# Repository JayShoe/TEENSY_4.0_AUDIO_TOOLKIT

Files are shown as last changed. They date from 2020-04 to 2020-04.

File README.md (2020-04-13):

# Teensy 4.0 Audio Toolkit and Shield
Licensed under CC BY-NC-SA 4.0
https://creativecommons.org/licenses/by-nc-sa/4.0/
Project by Jay Shoemaker

*Project is incomplete, accepting feedback now!

The Teensy 4.0 Audio Toolkit and Shield is part of an open source project for learning about, designing, and rapid-prototyping custom Audio PCBs using the Teensy Audio Library. This kit exposes key features of the Teensy commonly used for audio including USB Host Input, MIDI In, Midi Out, Midi Through, SPDIF, and Toslink. The board also includes an SD Memory Card reader, RAM/Memory, and a Power Supply. Plus, the schematic points out the key pins for connecting your own audio chips to the Teensy. This project is just exposing the hardware. Some functions may require additional work on the Teensy Audio Library or your custom code.  
 
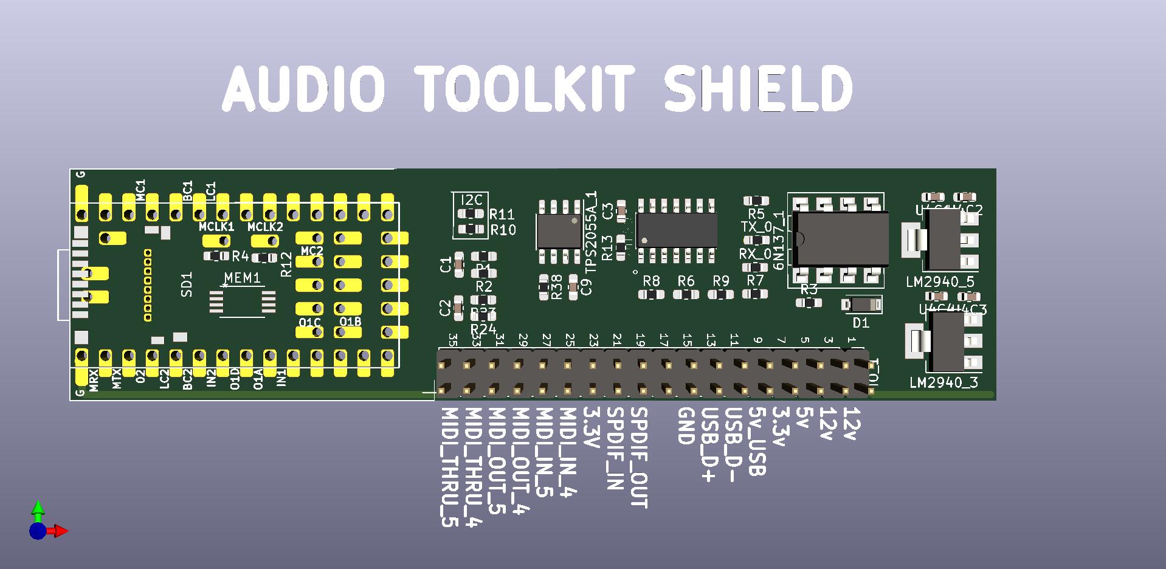
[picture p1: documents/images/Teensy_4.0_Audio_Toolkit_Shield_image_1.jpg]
Audio Toolkit Shield


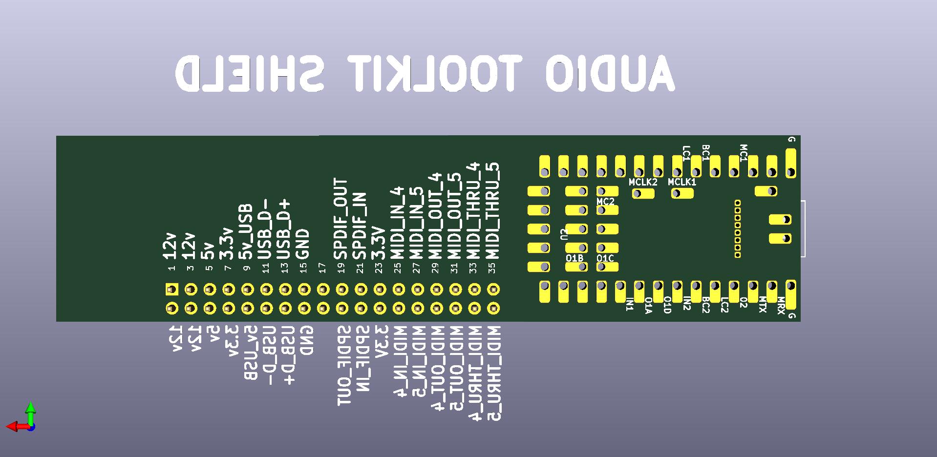
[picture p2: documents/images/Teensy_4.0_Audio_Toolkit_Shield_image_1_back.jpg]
Audio Toolkit Shield Back

 
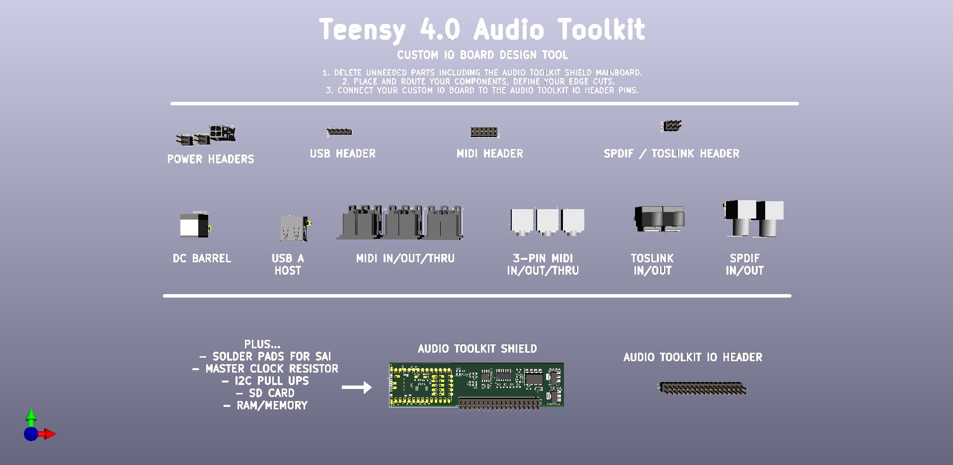
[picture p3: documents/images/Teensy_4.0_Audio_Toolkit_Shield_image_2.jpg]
Audio Toolkit


# Teensy Audio Toolkit and Shield's Key Features
 * Open Source CC BY-NC-SA 4.0
 * Stackable Design – To easily integrate with other stackable modules including DAC, ADC, Codec, Bluetooth, etc. 
 * Starting Point for Custom IO Panels – All inputs/outputs are only exposed as header pins. Use of a custom daughterboard, dongle, or soldering directly to the Audio Toolkit Mainboard to expose the desired jacks or ports. 
  * SD Card Reader  - via DM3D-SF Hirose Electric Co Ltd. 
  * Memory – via W25Q128JV, W25Q128FV, or 23LC1024 RAM. 
  * USB Host – via standard pinout USB Header and USB A connector and includes a TPS2055A current limiter chip. 
  * SPDIF Input and Output – via header, Coax, or Toslink.
  * MIDI In, Out, and Through – via header, DIN 5, or 3.5mm 3-pin Mini MIDI and includes an optocoupler (6N137) and a logic gate (74LS00) for proper termination. 
  * Power Supply – 1 Amp regulator for both 5V and 3.3V rails (LM2940) with an input voltage range of 6 V to 26 V. 
 * Footprints, 3d Models, and Schematics included. 
 * SAI Connectivity and Labels. The teensy footprint has been modified to include wide pads and pin information for standard I2S connectivity. Solder wire to those pads for an easy and secure connection to external DAC/ADC/CODEC/ETC. 
  * Master Clock - 100 Ohm resistors installed on MCLK1 and MCLK2 lines for easy connectivity. 
  * i2C - Pull up resistors on board for easy connectivity.
# Daughterboards with Jacks/Ports
The Audio Toolkit Shield’s header allows simple connections to one or more daughter boards. The mainboard and daughter board’s source and gerbers will be publicly available on the project repository. Pre-assembled boards will be made available (when tested/complete). Create your own daughterboard using the toolkit as a starting point. (Be sure to contribute back your modifications!)
## Designing a Custom Daughterboard
1.	Delete unneeded parts including the Audio Toolkit Mainboard. 
2.	Place and route your components. Define your edge cuts. Order your board. 
3.	Connect your customer IO Board to the Audio Toolkit Mainboard IO Header. 
## Audio Toolkit Notes
-	Use pre-built IO boards found within the project’s repository. 
-	Use the “Audio Toolkit IO Header” to stack your custom IO Board on top of the mainboard via the headers. 
-	Use the individual headers to create smaller custom IO Boards and link your project via ribbon cables, etc. 
-	Use the schematic to create your own entirely new custom Audio Toolkit or integrate it into your own project.

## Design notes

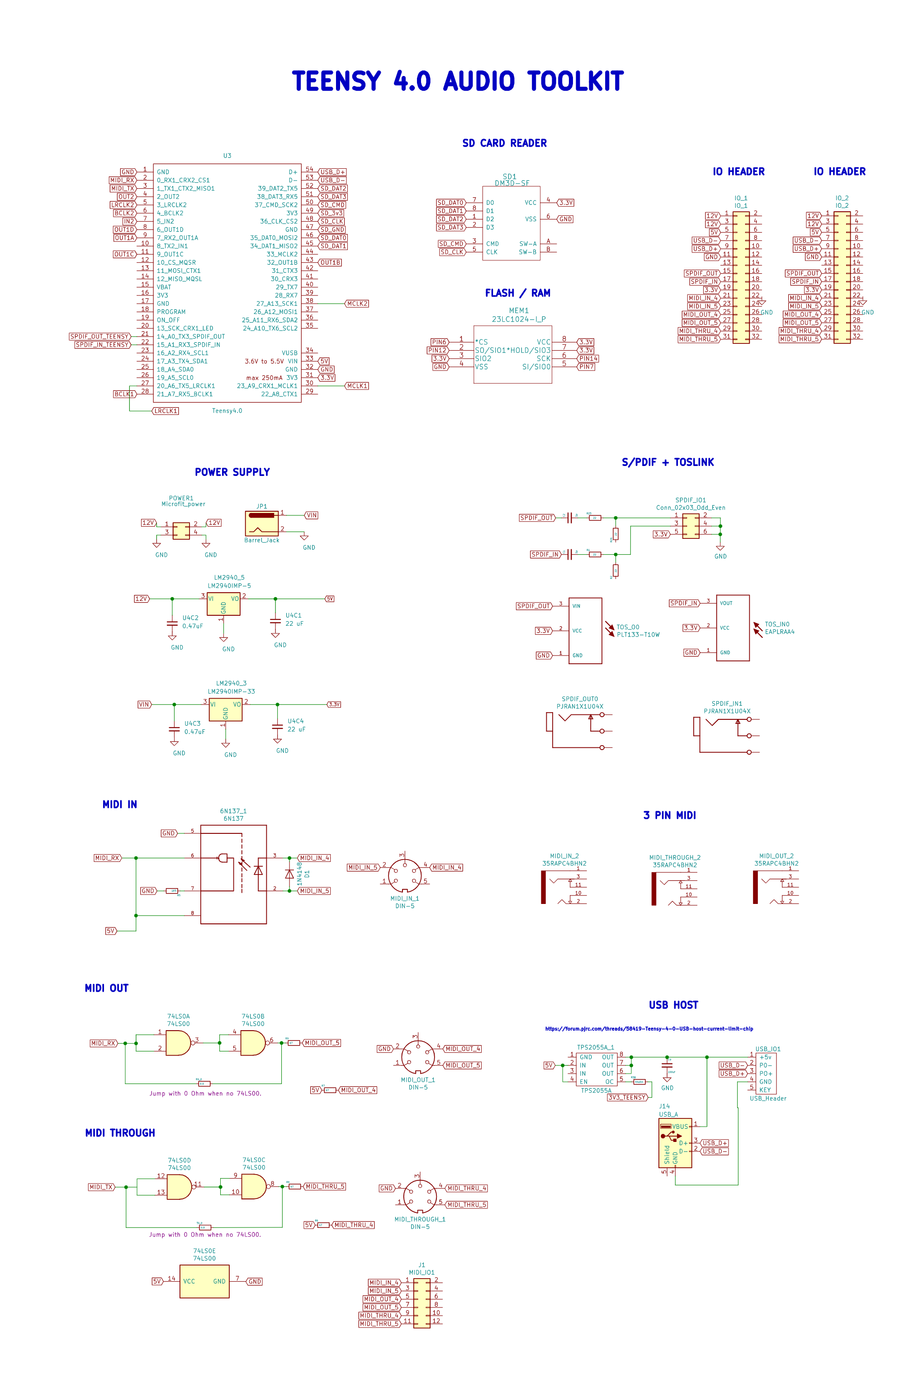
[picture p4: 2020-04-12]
documents/images/Teensy_4.0_Audio_Toolkit_Shield_Schematic_1.png

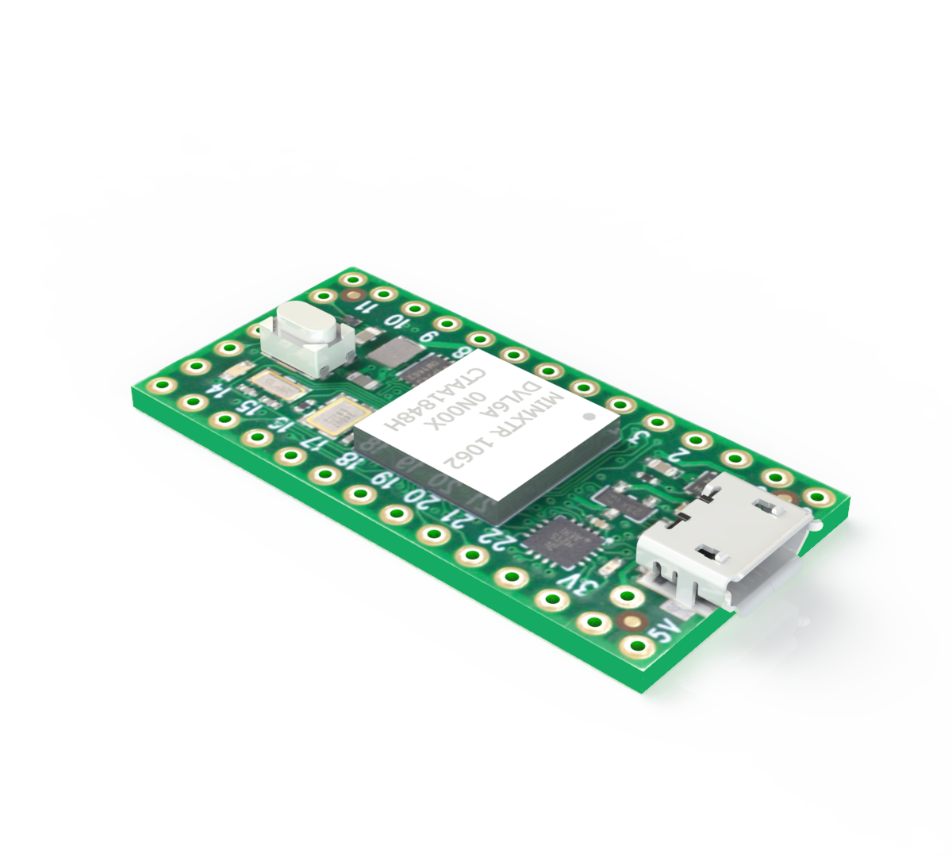
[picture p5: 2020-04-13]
3d_models/teensy-4-0-1.snapshot.3/Teensy_4.0/Renders/Teensy_4.0.png

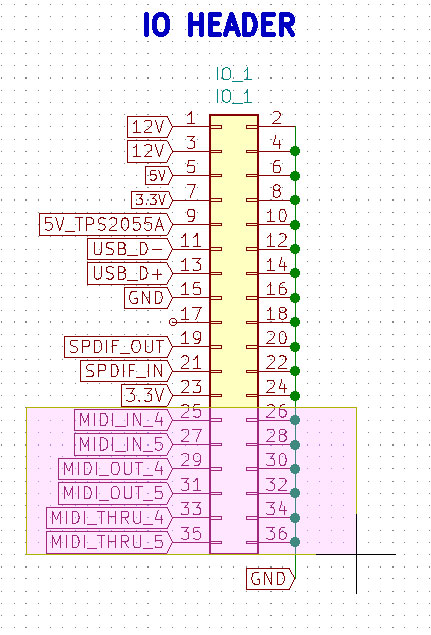
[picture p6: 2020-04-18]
documents/images/audio_toolkit_io_header.jpg

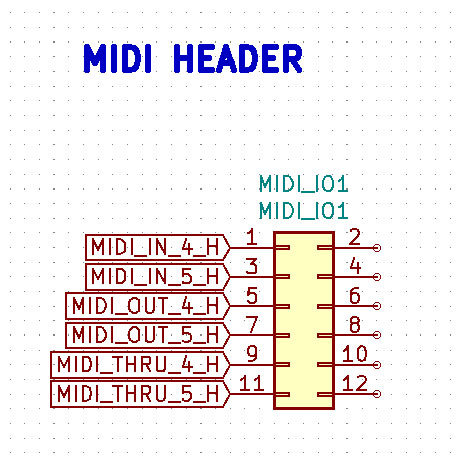
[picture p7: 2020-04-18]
documents/images/midi_header.jpg

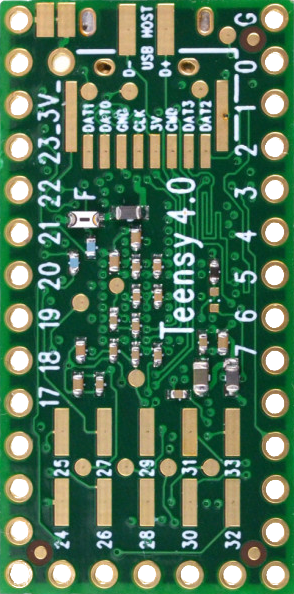
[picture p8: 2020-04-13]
3d_models/teensy-4-0-1.snapshot.3/Teensy_4.0/Teensy_4.0_Decal/Teensy_4.0_Back.png

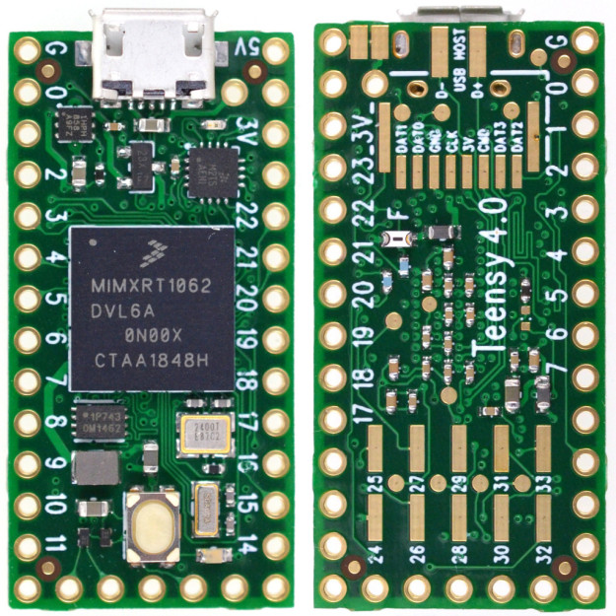
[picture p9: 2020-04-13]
3d_models/teensy-4-0-1.snapshot.3/Teensy_4.0/Teensy_4.0_Decal/teensy40-launch-frontandback-thumb.jpg

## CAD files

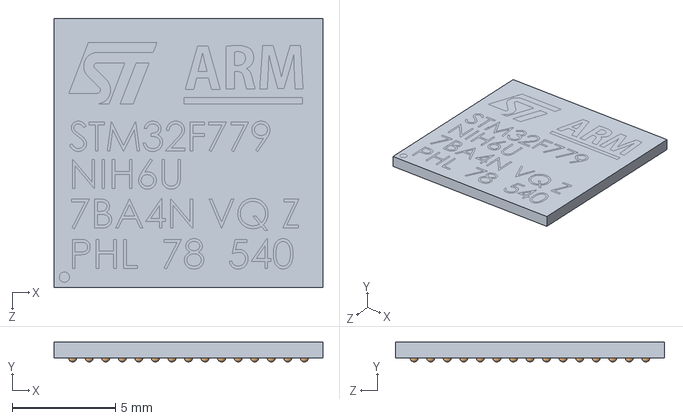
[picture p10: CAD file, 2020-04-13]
3d_models/teensy-4-0-1.snapshot.3/Teensy_4.0/STM32F779NIHx.SLDASM
13.0 x 0.96 x 13.0 mm
ball x 216

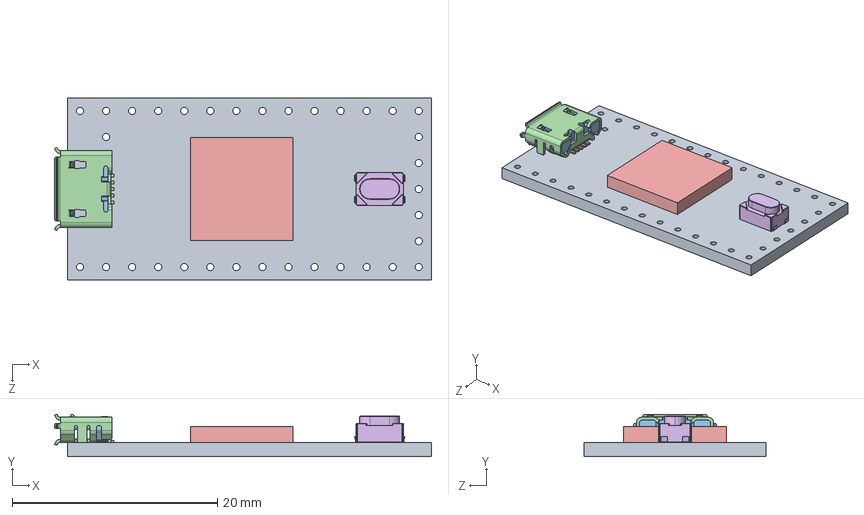
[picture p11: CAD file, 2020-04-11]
3d_models/teensy-4-0-1.snapshot.3/Teensy_4.0/Teensy_4.0_Assembly.STEP
36.8 x 4.12 x 17.7 mm
Teensy_4.0_PCB
Micro USB-B Female 5Pin SMD
NXP iMXRT1062
SKRPACE010 v4

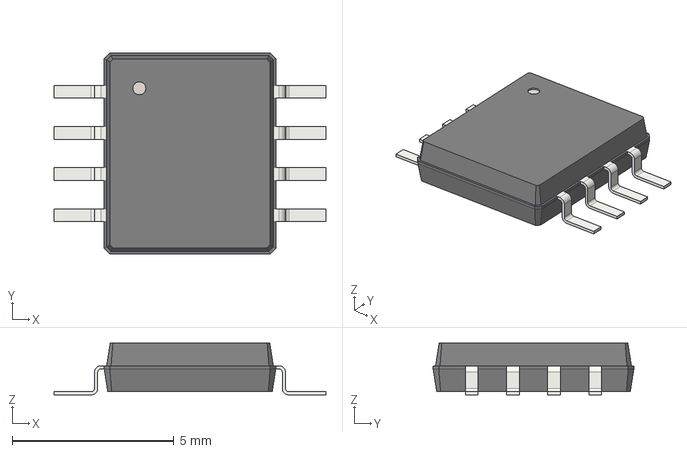
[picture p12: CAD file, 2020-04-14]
3d_models/SO-8_5.3x6.2mm_P1.27mm.step
8.40 x 6.20 x 1.60 mm

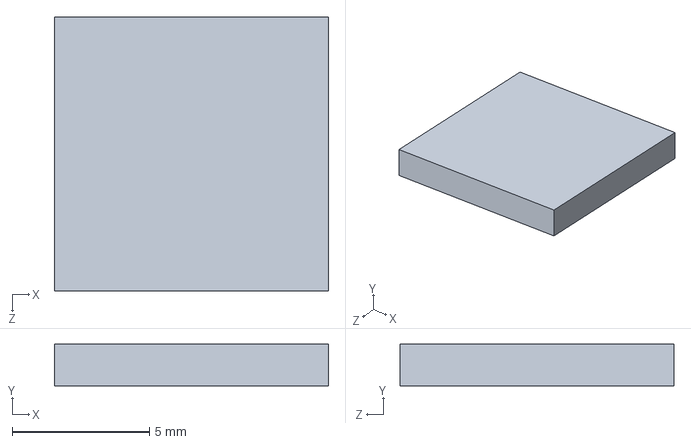
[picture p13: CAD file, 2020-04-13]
3d_models/teensy-4-0-1.snapshot.3/Teensy_4.0/NXP iMXRT1062.SLDPRT
10.0 x 1.52 x 10.0 mm

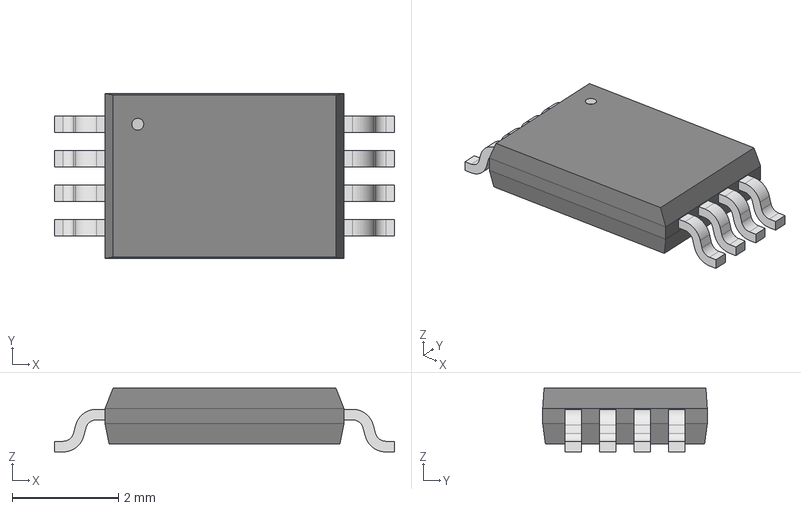
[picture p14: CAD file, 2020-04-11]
lib_sch/ul_23LC1024IST/2020-04-10_17-26-26/STEP/TSSOP8_MC.step
6.40 x 3.10 x 1.20 mm

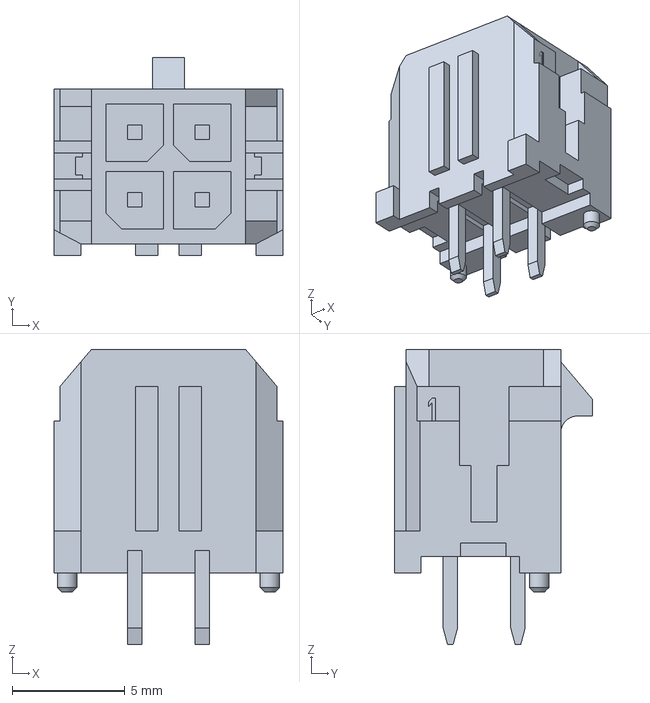
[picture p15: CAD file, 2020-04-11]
3d_models/MicroFit3-43045-0428.stp
10.1 x 8.77 x 13.1 mm

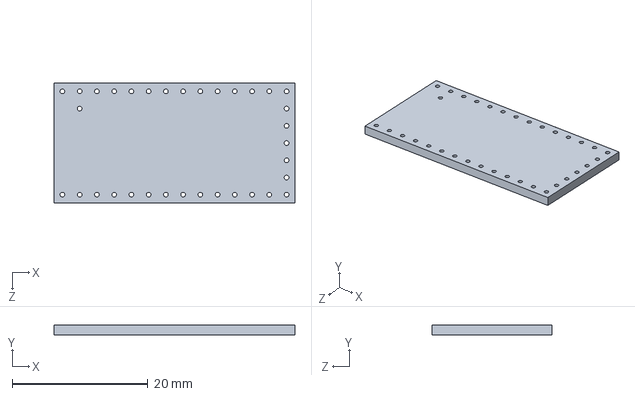
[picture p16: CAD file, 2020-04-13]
3d_models/teensy-4-0-1.snapshot.3/Teensy_4.0/Teensy_4.0_PCB.SLDPRT
35.5 x 1.40 x 17.7 mm

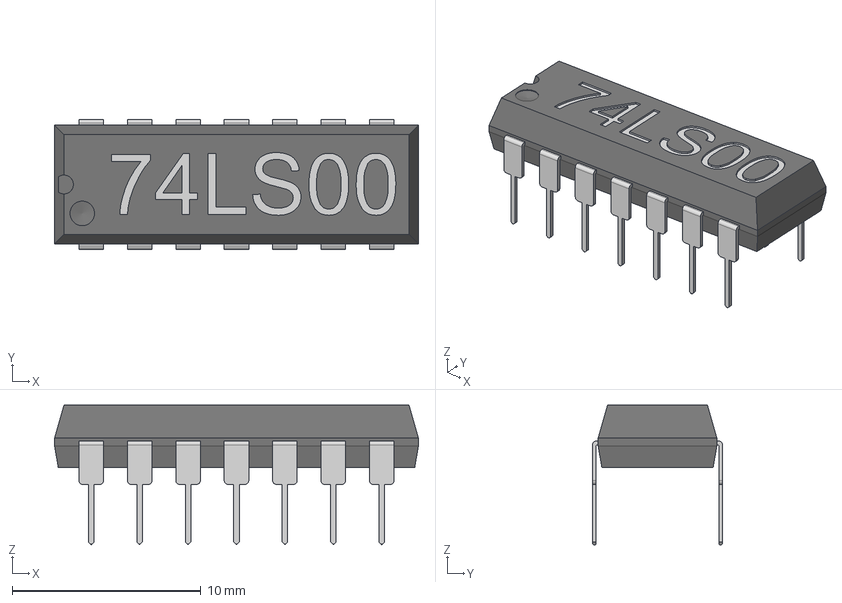
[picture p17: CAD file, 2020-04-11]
3d_models/74LS00.step
19.3 x 6.90 x 7.40 mm

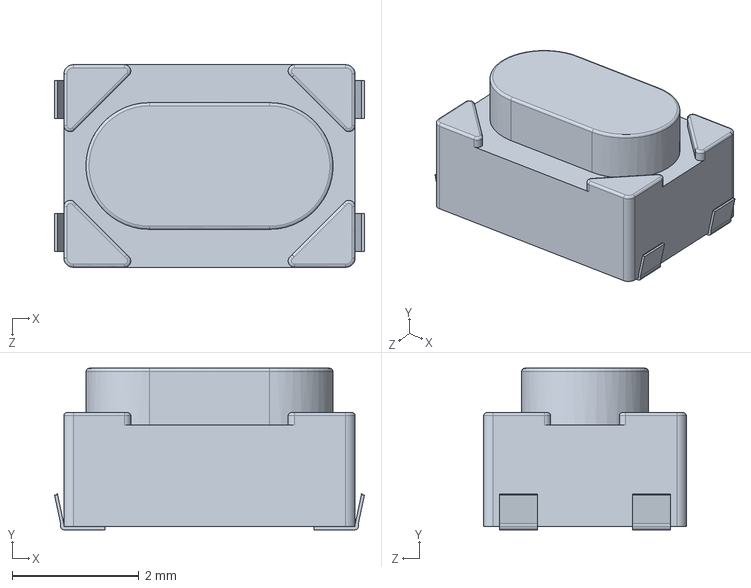
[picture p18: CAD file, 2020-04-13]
3d_models/teensy-4-0-1.snapshot.3/Teensy_4.0/SKRPACE010 v4.SLDPRT
4.89 x 2.55 x 3.20 mm

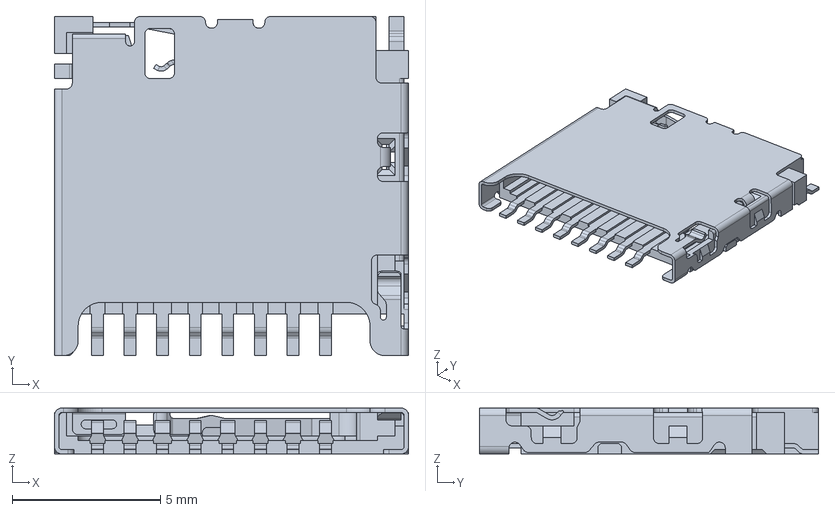
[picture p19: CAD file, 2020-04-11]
3d_models/SD_CARD_DM3D-SF.step
11.9 x 11.4 x 1.55 mm

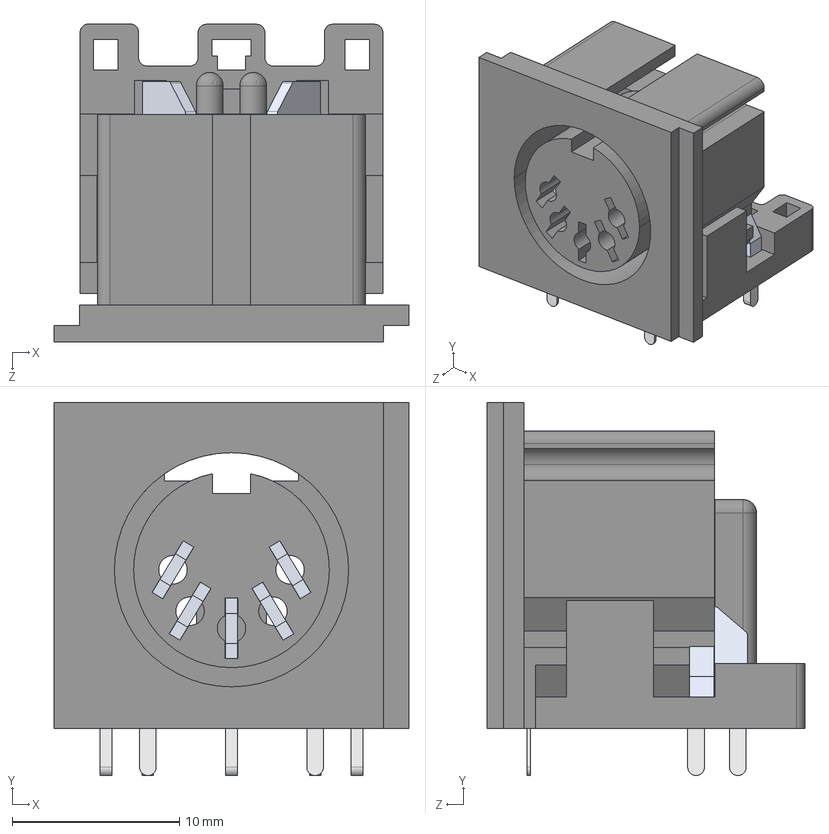
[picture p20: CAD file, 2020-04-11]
3d_models/DIN-5.STEP
21.2 x 22.3 x 19.0 mm
DIN5 A
DIN5 B
DIN5 C
DIN D x 2
DIN E x 2
DIN EE x 2
DIN G
DIN DD x 2

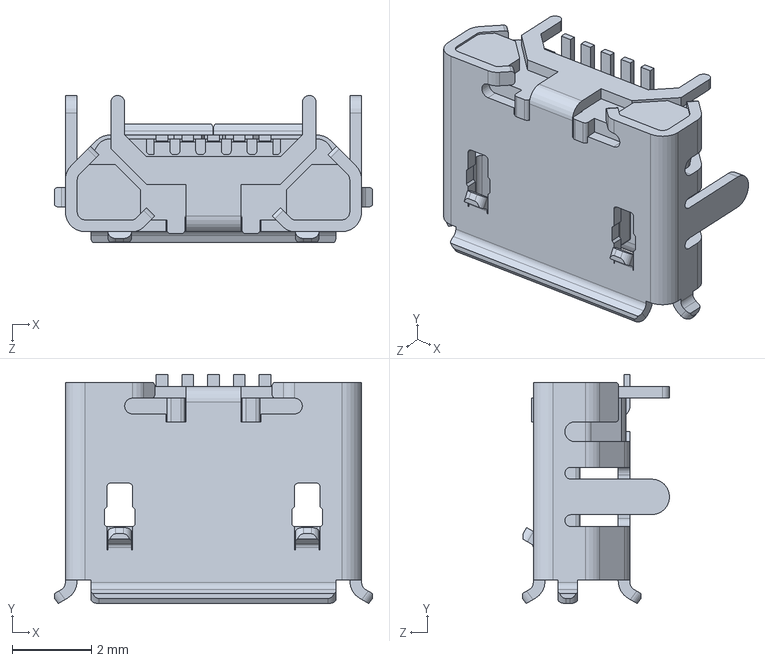
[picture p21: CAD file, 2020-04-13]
3d_models/teensy-4-0-1.snapshot.3/Teensy_4.0/Micro USB-B Female 5Pin SMD.SLDPRT
8.05 x 5.80 x 3.72 mm

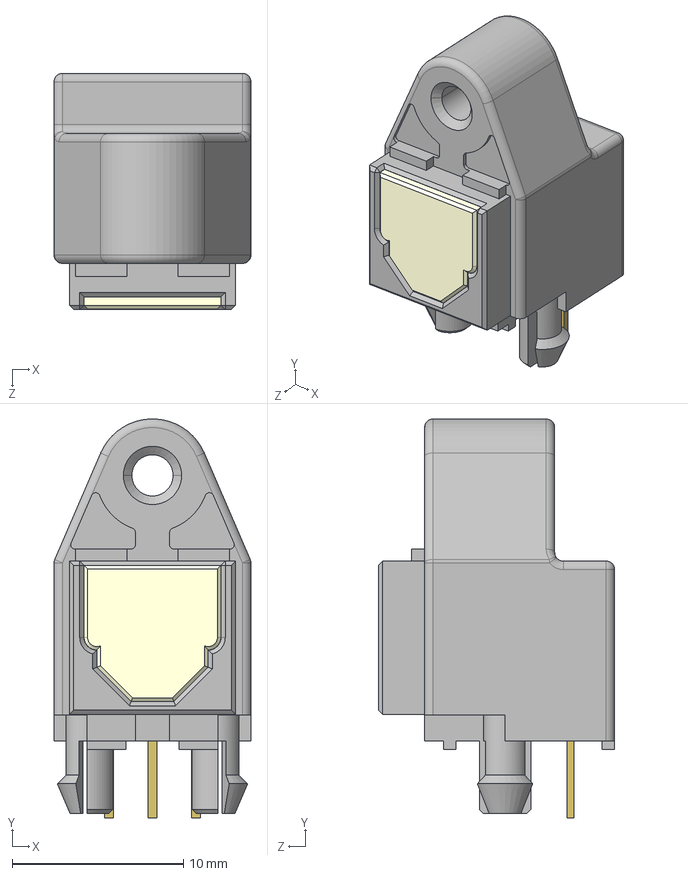
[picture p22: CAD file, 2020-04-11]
3d_models/TOSLINK_3D_MODEL_PLT133_T9.step
11.5 x 23.3 x 13.8 mm

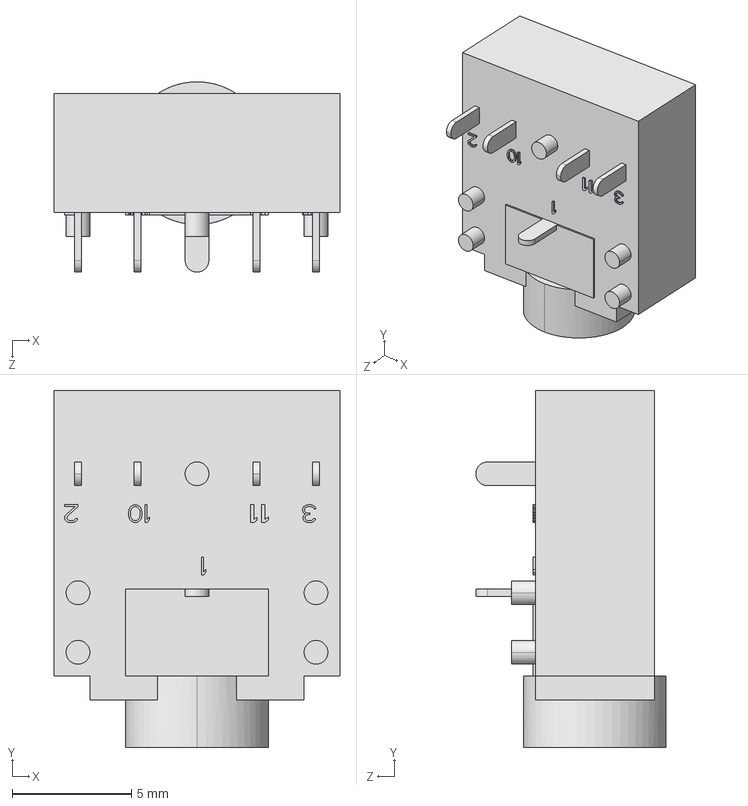
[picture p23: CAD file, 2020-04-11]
3d_models/3.5MM_STEREO_35RAPC4BHN2.STEP
12.0 x 15.0 x 8.00 mm

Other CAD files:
lib_sch/ul_23LC1024IST/2020-04-10_17-26-26/STEP/TSSOP8_MC-M.step
lib_sch/ul_23LC1024IST/2020-04-10_17-26-26/STEP/TSSOP8_MC-L.step
3d_models/SPDIF_pjran1x1_Series.STEP
3d_models/USB_A_c-292303-4-f-3d.stp
3d_models/DC_BARREL_PJ-202AH.step
3d_models/SOIC-14_3.9x8.7mm_P1.27mm.step
3d_models/teensy-4-0-1.snapshot.3/Teensy_4.0/Teensy_4.0_Assembly.SLDASM

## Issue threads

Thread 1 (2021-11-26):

Interface options to Raspberry Pi

kryptolix, 2021-11-26:
Hey,
I have a very specific project in mind, where I need a 4 or better 6 channel ADC. It will eventually run on a RPi.
Is this Teensy behaving to USB like a audio interface? Would I be able to get the audio to the raspberry? My problem is, that the Pi only has I2S and probably doesn't accept multichannel vie I2S/TDM. But I am able to access a USB multichannel Interface.
So, would your ADC/Teensy act like a USB interface, if I plug it into a Pi or any other computer, so that I could access it via pipewire or jack?

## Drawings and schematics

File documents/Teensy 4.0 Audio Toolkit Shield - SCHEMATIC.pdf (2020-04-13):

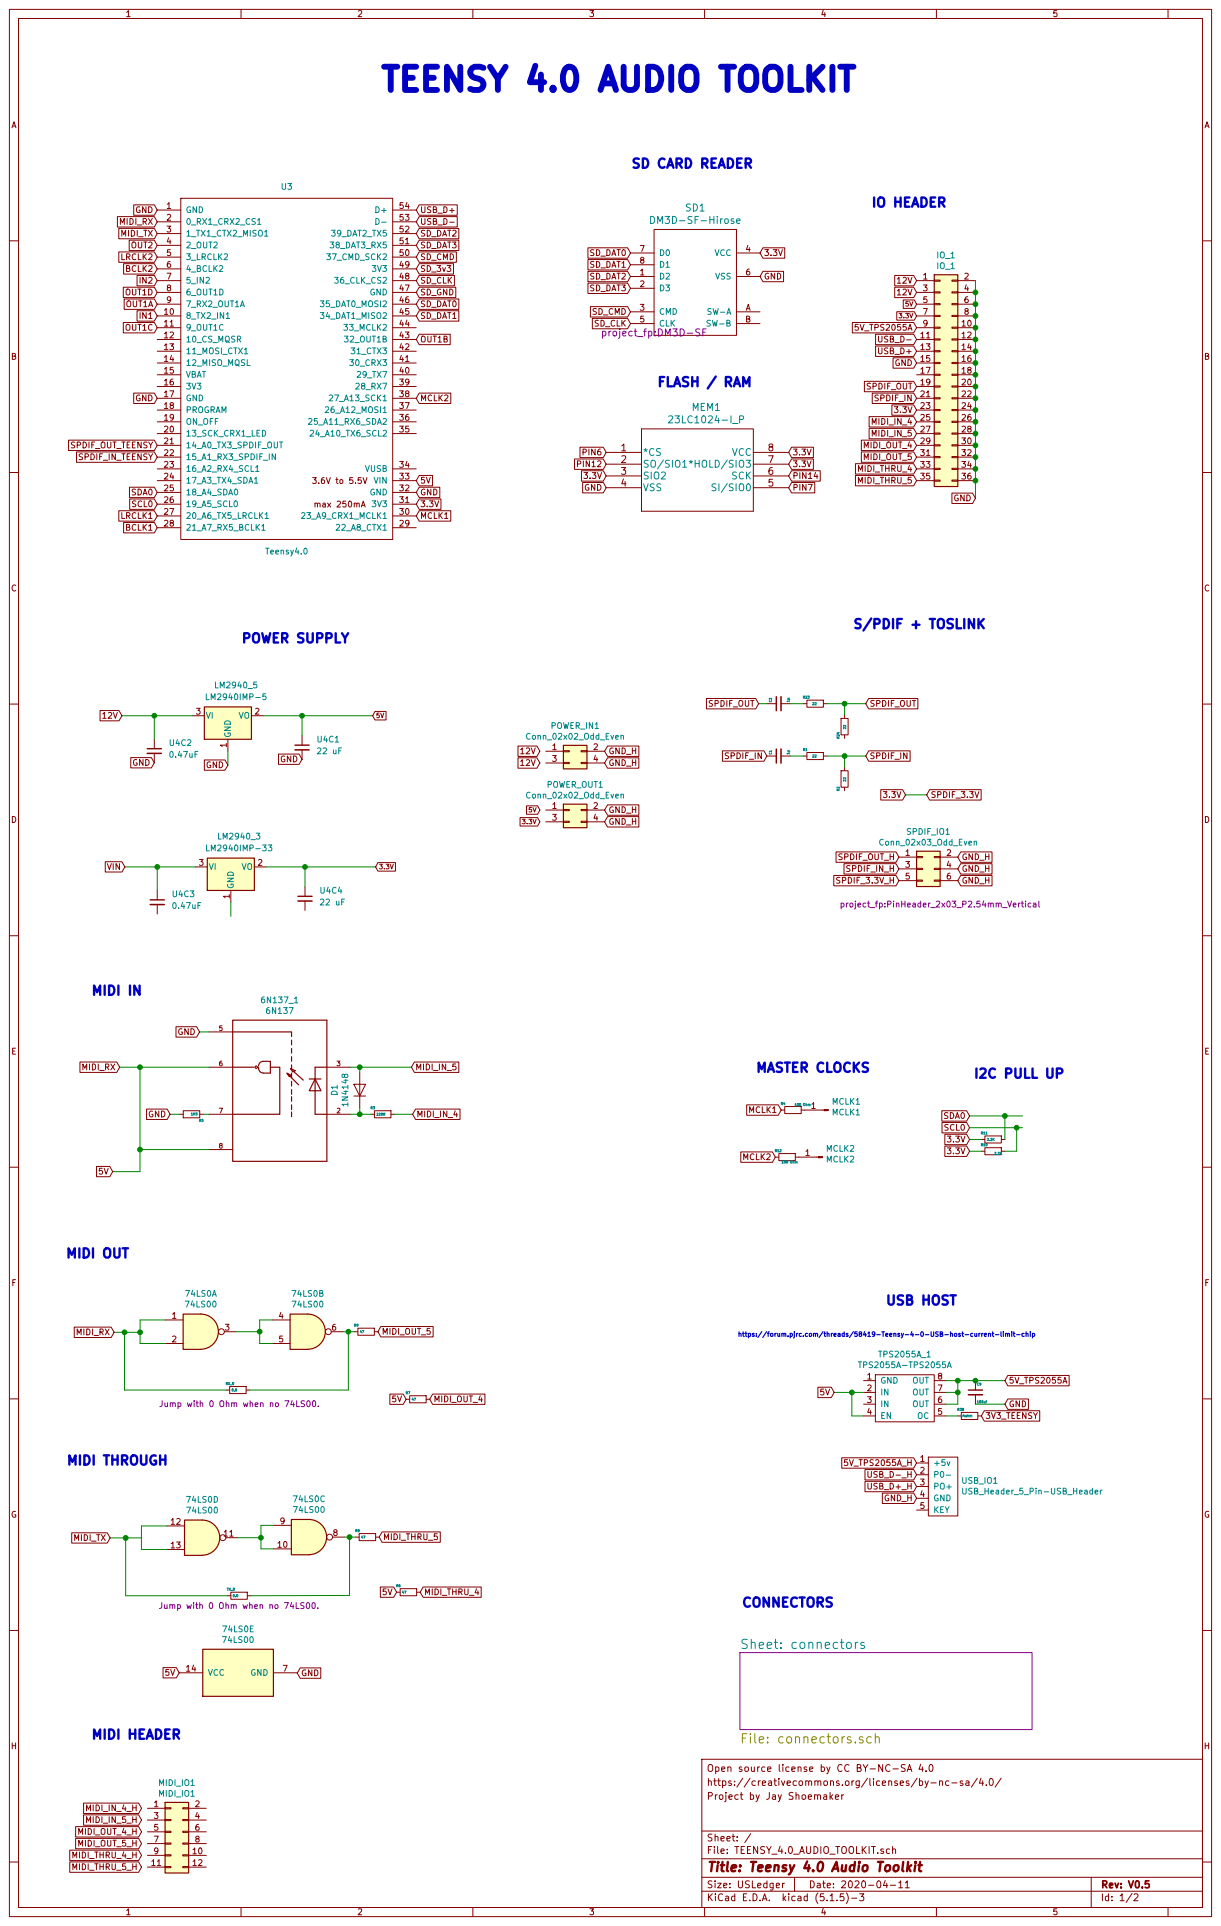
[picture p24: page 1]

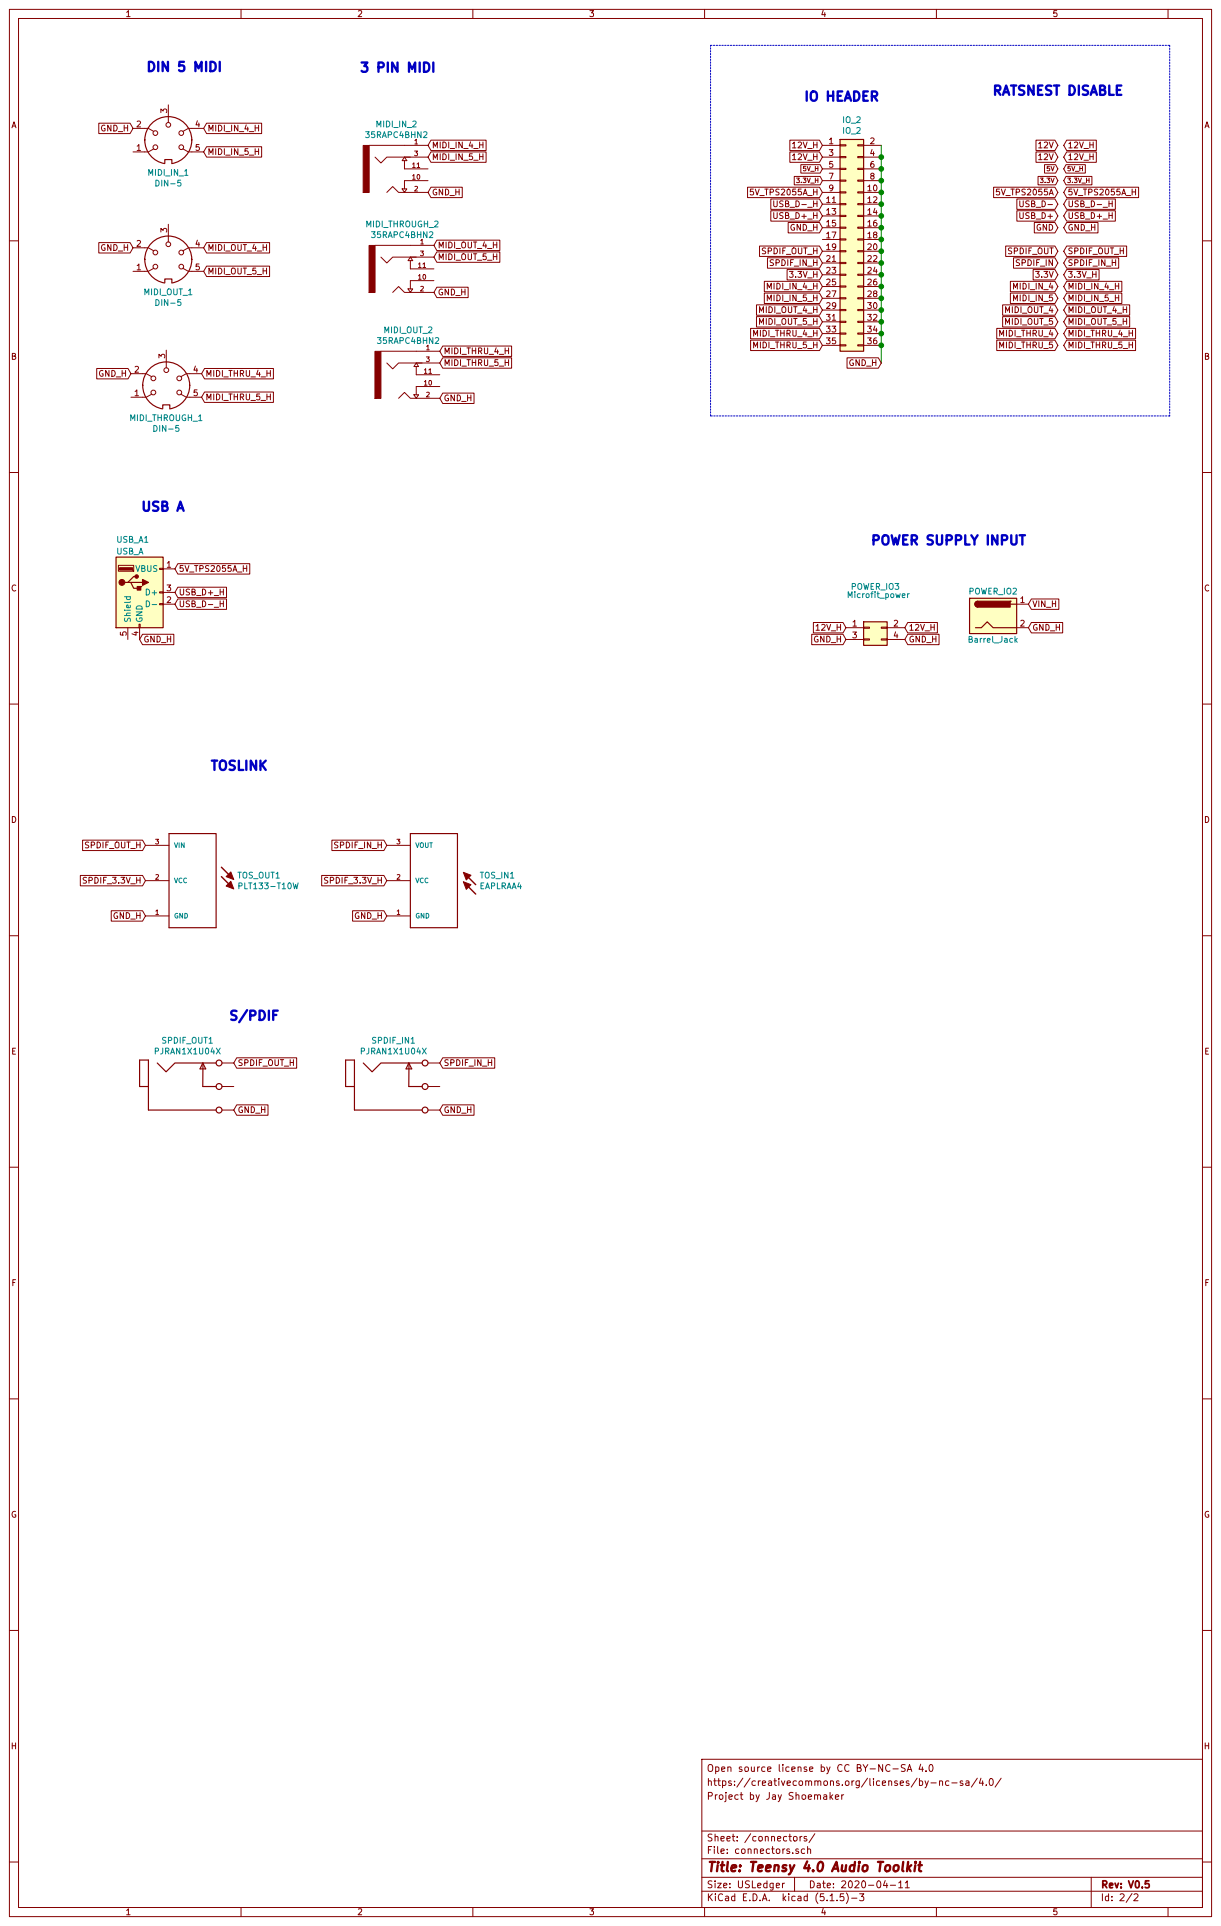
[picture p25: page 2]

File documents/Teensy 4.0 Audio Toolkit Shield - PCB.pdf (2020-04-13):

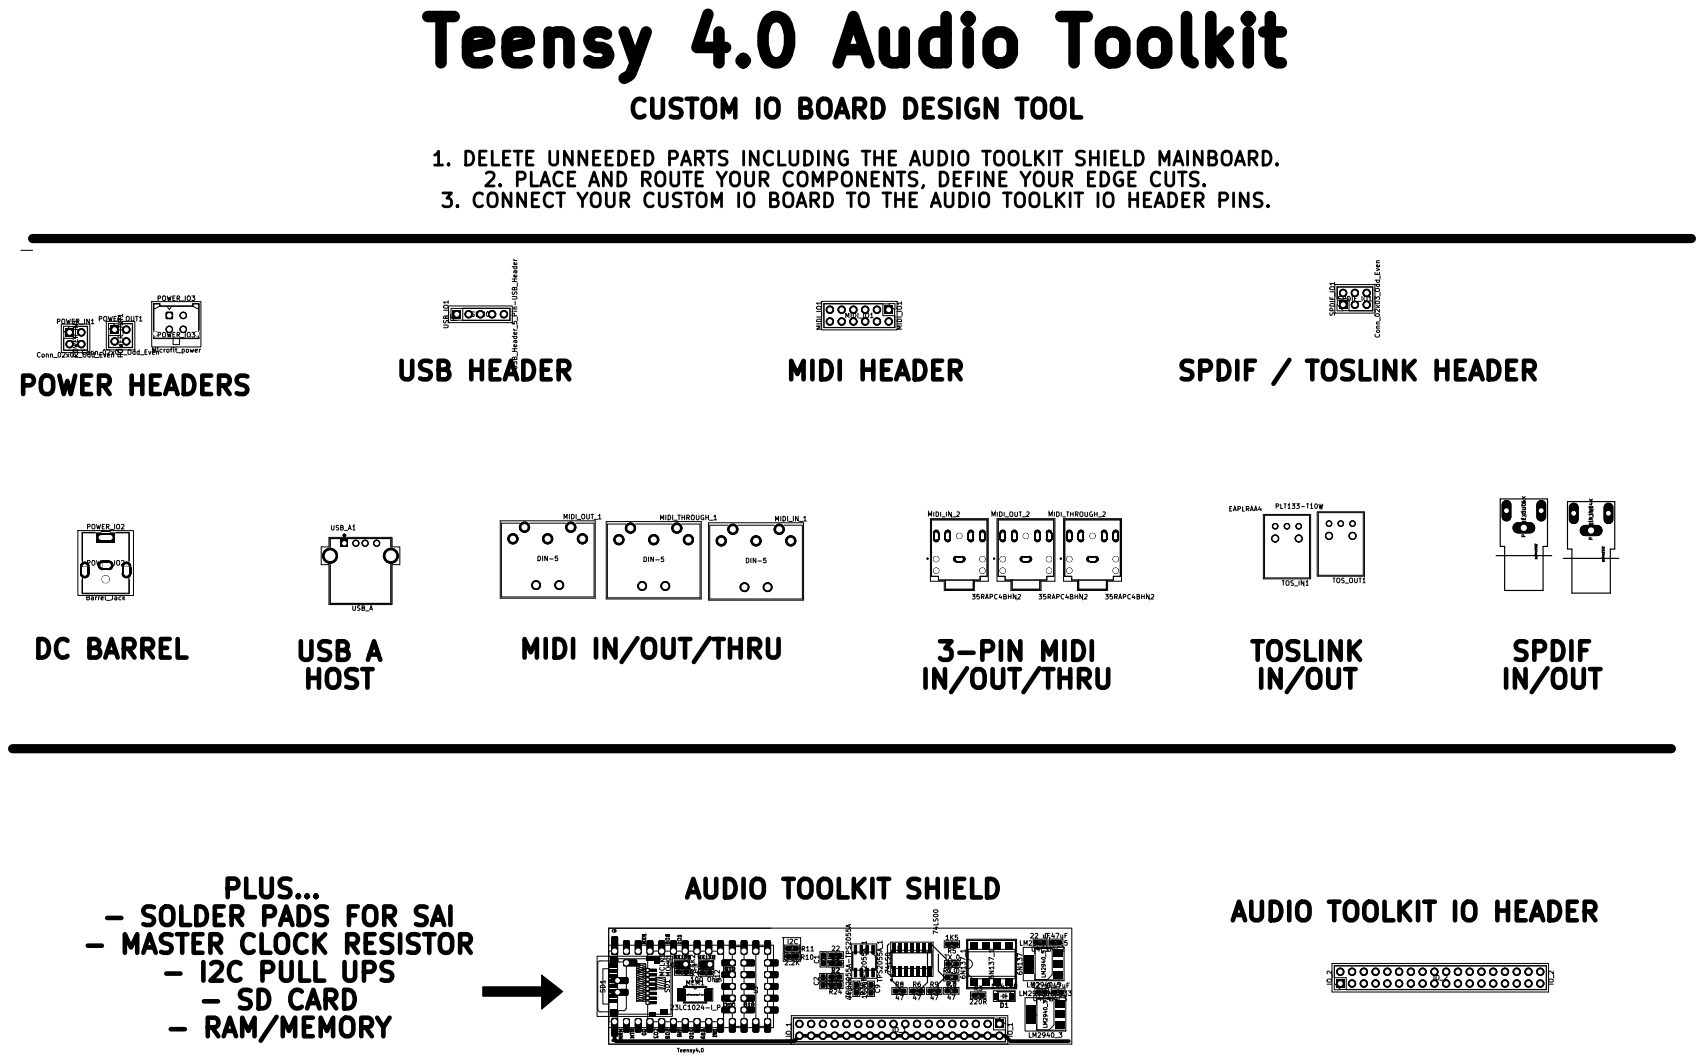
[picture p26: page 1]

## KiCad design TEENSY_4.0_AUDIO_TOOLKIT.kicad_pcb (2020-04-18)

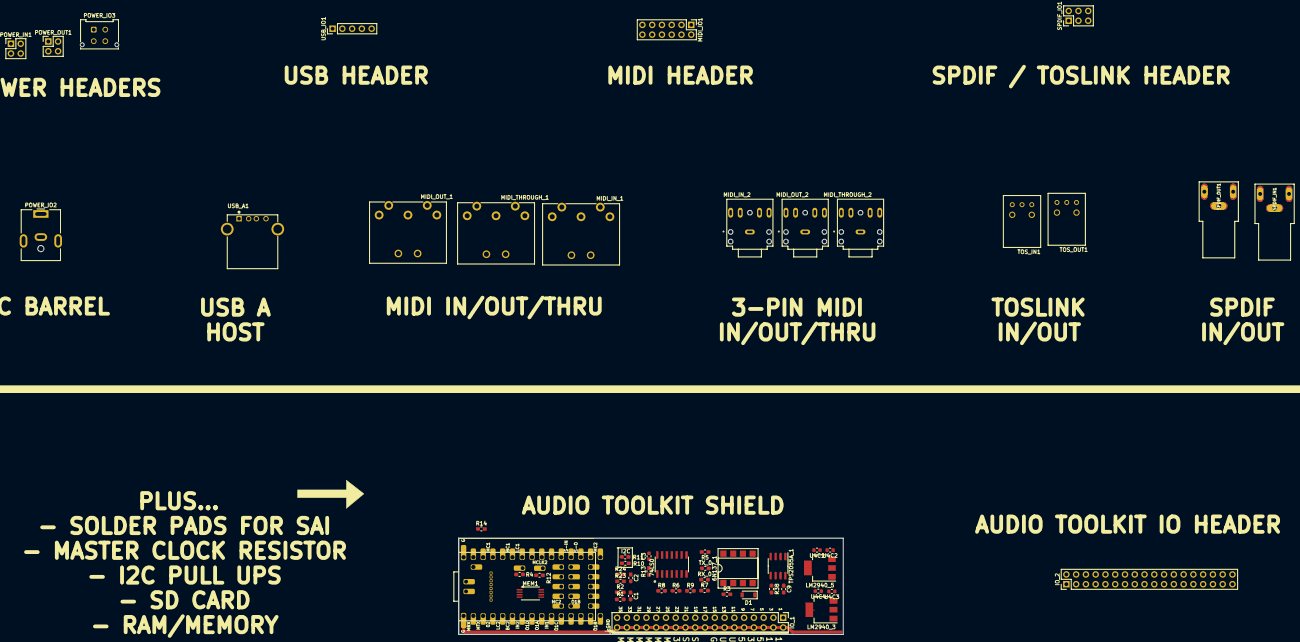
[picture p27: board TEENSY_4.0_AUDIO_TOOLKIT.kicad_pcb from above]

Board: 2 copper layers, 100.0 x 25.0 mm, 58 parts (1 on the bottom side), 56 nets.

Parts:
6N137_1: 6N137; DIP-8_W7.62mm_SMDSocket_SmallPads
74LS0: 74LS00; 74LS00_SOIC127P600X175-14N
C1, C2: 1μ; C_0603_1608Metric_Pad1.05x0.95mm_HandSolder
C3: .1 uF; C_0603_1608Metric
C9: 100uf; C_0603_1608Metric_Pad1.05x0.95mm_HandSolder
D1: 1N4148; D_SOD-123
IO_1: IO_1; PinHeader_2x18_P2.54mm_Vertical
IO_2: IO_2; PinHeader_2x18_P2.54mm_Vertical
LM2940_3: LM2940IMP-33; SOT-223
LM2940_5: LM2940IMP-5; SOT-223
MCLK1: MCLK1; SolderWirePad_1x01_THROUGH_SOLDER
MCLK2: MCLK2; SolderWirePad_1x01_THROUGH_SOLDER
MEM1: 23LC1024-I_P; 23LC1024
MIDI_IN_1: DIN-5; SDS-50J_MIDI_JACK
MIDI_IN_2: 35RAPC4BHN2; 3.5MM_SWITCHCRAFT_35RAPC4BHN2
MIDI_IO1: MIDI_IO1; PinHeader_2x06_P2.54mm_Vertical
MIDI_OUT_1: DIN-5; SDS-50J_MIDI_JACK
MIDI_OUT_2: 35RAPC4BHN2; 3.5MM_SWITCHCRAFT_35RAPC4BHN2
MIDI_THROUGH_1: DIN-5; SDS-50J_MIDI_JACK
MIDI_THROUGH_2: 35RAPC4BHN2; 3.5MM_SWITCHCRAFT_35RAPC4BHN2
POWER_IN1: Conn_02x02_Odd_Even; PinHeader_2x02_P2.54mm_Vertical
POWER_IO2: Barrel_Jack; BarrelJack_CUI_PJ-063AH_Horizontal
POWER_IO3: Microfit_power; Molex_Micro-Fit_3.0_43045-0412_2x02_P3.00mm_Vertical
POWER_OUT1: Conn_02x02_Odd_Even; PinHeader_2x02_P2.54mm_Vertical
R1, R2, R23, R24: 22; R_0603_1608Metric_Pad1.05x0.95mm_HandSolder
R3, R14: 220R; R_0603_1608Metric_Pad1.05x0.95mm_HandSolder
R4, R12: 100 Ohm; R_0603_1608Metric_Pad1.05x0.95mm_HandSolder
R5: 1K5; R_0603_1608Metric_Pad1.05x0.95mm_HandSolder
R6, R9: 220; R_0603_1608Metric_Pad1.05x0.95mm_HandSolder
R7, R8: 47; R_0603_1608Metric_Pad1.05x0.95mm_HandSolder
R10, R11: 2.2K; R_0603_1608Metric_Pad1.05x0.95mm_HandSolder
R13: 470; R_0603_1608Metric_Pad1.05x0.95mm_HandSolder
R38: 44ohm; R_0603_1608Metric_Pad1.05x0.95mm_HandSolder
RX_0: 0.0; R_0603_1608Metric_Pad1.05x0.95mm_HandSolder
SD1: DM3D-SF-Hirose; DM3D-SF
SPDIF_IN1: PJRAN1X1U04X; SPDIF_PJRAN1X1U01X
SPDIF_IO1: Conn_02x03_Odd_Even; PinHeader_2x03_P2.54mm_Vertical
SPDIF_OUT1: PJRAN1X1U04X; SPDIF_PJRAN1X1U01X
TOS_IN1: EAPLRAA4; PLR135-T10_PLT133-T10W
TOS_OUT1: PLT133-T10W; PLR135-T10_PLT133-T10W
TPS2055A_1: TPS2055A-TPS2055A; SOIC-8_3.9x4.9mm_P1.27mm
TX_0: 0.0; R_0603_1608Metric_Pad1.05x0.95mm_HandSolder
U3: Teensy4.0; Teensy40_SMT_Audio_Kit_2
U4C1, U4C4: 22 uF; C_0603_1608Metric
U4C2, U4C3: 0.47uF; C_0603_1608Metric
USB_A1: USB_A; TE_292303-4
USB_IO1: USB_Header_5_Pin-USB_Header; PinHeader_1x05_P2.54mm_Vertical

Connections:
3.3V: IO_1.7, IO_1.23, LM2940_3.2, MEM1.3, MEM1.7, MEM1.8, R10.2, R11.2, SD1.4, U3.31, U4C4.1
3.3V_H: IO_2.7, IO_2.23, POWER_OUT1.3
5V: 6N137_1.8, 74LS0.14, C3.2, IO_1.5, LM2940_5.2, R6.2, R7.2, TPS2055A_1.2, TPS2055A_1.4, U3.33, U4C1.1
5V_H: IO_2.5, POWER_OUT1.1
5V_TPS2055A: C9.1, IO_1.9, TPS2055A_1.6, TPS2055A_1.7, TPS2055A_1.8
5V_TPS2055A_H: IO_2.9, USB_A1.1, USB_IO1.1
12V: IO_1.1, IO_1.3, LM2940_5.3, U4C2.1
12V_H: IO_2.1, IO_2.3, POWER_IN1.1, POWER_IN1.3, POWER_IO3.1, POWER_IO3.2
GND: 6N137_1.5, 74LS0.7, C3.1, C9.2, IO_1.2, IO_1.4, IO_1.6, IO_1.8, IO_1.10, IO_1.12, IO_1.14, IO_1.15, IO_1.16, IO_1.18, IO_1.20, IO_1.22, IO_1.24, IO_1.26, IO_1.28, IO_1.30, IO_1.32, IO_1.34, IO_1.36, LM2940_3.1, LM2940_5.1, MEM1.4, R2.2, R5.1, R24.2, SD1.6, U3.1, U3.17, U3.32, U4C1.2, U4C2.2, U4C3.2, U4C4.2
GND_H: IO_2.2, IO_2.4, IO_2.6, IO_2.8, IO_2.10, IO_2.12, IO_2.14, IO_2.15, IO_2.16, IO_2.18, IO_2.20, IO_2.22, IO_2.24, IO_2.26, IO_2.28, IO_2.30, IO_2.32, IO_2.34, IO_2.36, MIDI_IN_1.2, MIDI_IN_2.2, MIDI_OUT_1.2, MIDI_OUT_2.2, MIDI_THROUGH_1.2, MIDI_THROUGH_2.2, POWER_IN1.2, POWER_IN1.4, POWER_IO2.2, POWER_IO3.3, POWER_IO3.4, POWER_OUT1.2, POWER_OUT1.4, SPDIF_IN1.1, SPDIF_IO1.2, SPDIF_IO1.4, SPDIF_IO1.6, SPDIF_OUT1.1, TOS_IN1.1, TOS_OUT1.1, USB_A1.4, USB_IO1.4
MCLK1: R4.2, U3.30
MCLK2: R12.2, U3.44
MIDI_IN_4: IO_1.25, R3.1
MIDI_IN_4_H: IO_2.25, MIDI_IN_1.4, MIDI_IN_2.1, MIDI_IO1.1
MIDI_IN_5: 6N137_1.3, D1.2, IO_1.27
MIDI_IN_5_H: IO_2.27, MIDI_IN_1.5, MIDI_IN_2.3, MIDI_IO1.3
MIDI_OUT_4: IO_1.29, R7.1
MIDI_OUT_4_H: IO_2.29, MIDI_IO1.5, MIDI_OUT_1.4, MIDI_THROUGH_2.1
MIDI_OUT_5: IO_1.31, R9.1
MIDI_OUT_5_H: IO_2.31, MIDI_IO1.7, MIDI_OUT_1.5, MIDI_THROUGH_2.3
MIDI_RX: 6N137_1.6, 74LS0.1, 74LS0.2, R13.2, RX_0.2, U3.2
MIDI_THRU_4: IO_1.33, R6.1
MIDI_THRU_4_H: IO_2.33, MIDI_IO1.9, MIDI_OUT_2.1, MIDI_THROUGH_1.4
MIDI_THRU_5: IO_1.35, R8.1
MIDI_THRU_5_H: IO_2.35, MIDI_IO1.11, MIDI_OUT_2.3, MIDI_THROUGH_1.5
MIDI_TX: 74LS0.12, 74LS0.13, TX_0.2, U3.3
unnamed: 6N137_1.2, D1.1, R3.2
unnamed: 6N137_1.7, R5.2
unnamed: 74LS0.3, 74LS0.4, 74LS0.5
unnamed: 74LS0.6, R9.2, RX_0.1
unnamed: 74LS0.8, R8.2, TX_0.1
unnamed: 74LS0.9, 74LS0.10, 74LS0.11
unnamed: C1.2, R1.2
unnamed: C2.2, R23.2
unnamed: MCLK1.1, R4.1
unnamed: MCLK2.1, R12.1
unnamed: R38.2, TPS2055A_1.5
OUT1B: R14.1, U3.43
SCL0: R10.1, U3.26
SDA0: R11.1, U3.25
SD_CLK: SD1.5, U3.48
SD_CMD: SD1.3, U3.50
SD_DAT0: SD1.7, U3.46
SD_DAT1: SD1.8, U3.45
SD_DAT2: SD1.1, U3.52
SD_DAT3: SD1.2, U3.51
SPDIF_3.3V_H: SPDIF_IO1.5, TOS_IN1.2, TOS_OUT1.2
SPDIF_IN: C1.1, IO_1.21, R1.1, R2.1
SPDIF_IN_H: IO_2.21, SPDIF_IN1.2, SPDIF_IO1.3, TOS_IN1.3
SPDIF_OUT: C2.1, IO_1.19, R23.1, R24.1
SPDIF_OUT_H: IO_2.19, SPDIF_IO1.1, SPDIF_OUT1.2, TOS_OUT1.3
USB_D+: IO_1.13, U3.54
USB_D+_H: IO_2.13, USB_A1.3, USB_IO1.3
USB_D-: IO_1.11, U3.53
USB_D-_H: IO_2.11, USB_A1.2, USB_IO1.2
VIN: LM2940_3.3, U4C3.1

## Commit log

2020-04-12 Added SAI Expansion Headers
    [TEENSY_4.0_AUDIO_TOOLKIT.kicad_pcb, TEENSY_4.0_AUDIO_TOOLKIT.sch]
2020-04-13 Added labels to IO
    [TEENSY_4.0_AUDIO_TOOLKIT.kicad_pcb]
2020-04-14 Update TEENSY_4.0_AUDIO_TOOLKIT.sch
    MCLK2 was on the wrong pin.
    [TEENSY_4.0_AUDIO_TOOLKIT.sch]

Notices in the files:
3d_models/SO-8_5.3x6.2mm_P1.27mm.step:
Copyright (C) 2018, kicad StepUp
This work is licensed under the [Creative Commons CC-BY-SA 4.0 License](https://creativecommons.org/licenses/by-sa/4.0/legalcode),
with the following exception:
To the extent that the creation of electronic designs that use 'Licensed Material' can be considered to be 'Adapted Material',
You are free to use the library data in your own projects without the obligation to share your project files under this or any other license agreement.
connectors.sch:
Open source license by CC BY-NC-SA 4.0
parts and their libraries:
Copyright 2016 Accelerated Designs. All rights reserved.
